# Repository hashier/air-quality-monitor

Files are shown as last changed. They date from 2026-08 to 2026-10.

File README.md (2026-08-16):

# air-quality-monitor

DIY air quality monitor on an ESP32-C6, running ESPHome and reporting to Home Assistant.

## Hardware

- **ESP32-C6** dev board (`esp32-c6-devkitc-1`)
- **Sensirion SCD40**: CO2, temperature, humidity (I2C `0x62`)
- **Sensirion SPS30**: particulate matter PM1.0 / 2.5 / 4.0 / 10.0 (I2C `0x69`, 5V)
- **SSD1306** 128x64 OLED (I2C `0x3C`)
- **WS2812** RGB LED (GPIO8)

All three sensors share one I2C bus at 100 kHz (the SPS30 datasheet ceiling).

## Repo layout

- `esphome/`: firmware (ESPHome config + secrets template)
- `kicad/`: custom PCB (planned)
- `case/`: 3D-printed enclosure (planned)

## Firmware

```fish
cd esphome
cp secrets.yaml.example secrets.yaml   # then fill in real values
esphome run air-quality-monitor.yaml
```

`secrets.yaml` holds WiFi / API / OTA credentials and is gitignored. Never commit it.

## Notes

- **SCD40 auto-recovery:** the sensor can get knocked out of periodic measurement (a flaky power connection resets it). A YAML watchdog detects CO2 going stale and re-inits it over raw I2C (stop, then start). Two Home Assistant diagnostics track this: `CO2 Stall Count` and `CO2 Currently Stalled`.
- **Temperature offset** (`6.5C`) is a provisional self-heating correction for the breadboard build. Re-tune in the final enclosure by comparing side by side against a reference.
- **Warm-up filters** drop the SCD40 startup transient (temperature/humidity 5 min, CO2 30 s).

## Status

Work in progress: currently on a breadboard. Custom PCB and enclosure are next.

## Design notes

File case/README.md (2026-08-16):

# case

3D-printed enclosure for the air quality monitor. Planned.

Design points: passive vents by the SCD40 for ambient diffusion (no direct
draft), a ducted intake and a separate exhaust for the SPS30 fan (kept away
from the SCD40), and the OLED plus RGB LED on the front face.

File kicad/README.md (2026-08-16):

# kicad

Custom PCB design (KiCad) for the air quality monitor. Planned.

Target layout: thermal zoning so the SCD40 sits away from the ESP32 and
regulator heat and the SPS30 exhaust, on a slot-isolated peninsula, with the
SPS30 airflow ducted to separate case vents. See the project notes for details.

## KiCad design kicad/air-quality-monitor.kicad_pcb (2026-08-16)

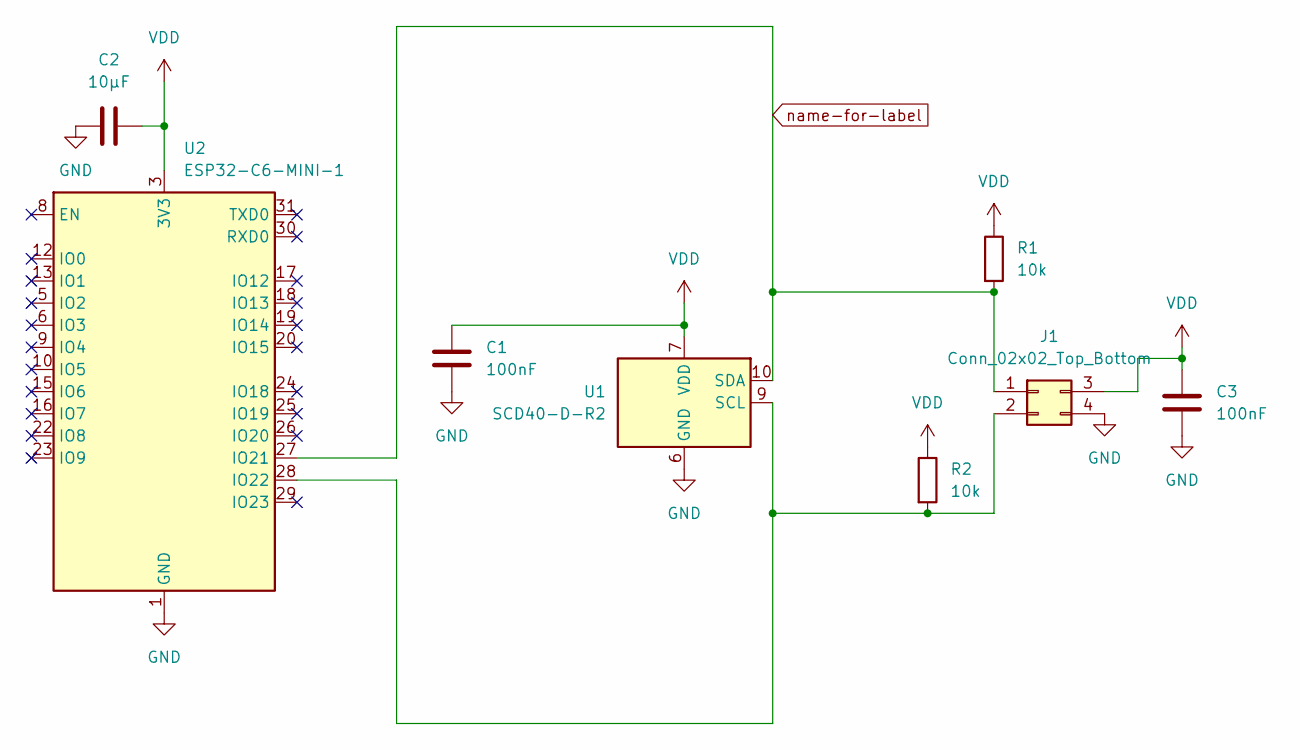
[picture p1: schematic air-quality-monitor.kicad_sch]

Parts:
C1, C3: 100nF; C_0603_1608Metric_Pad1.08x0.95mm_HandSolder
C2: 10µF; C_0603_1608Metric_Pad1.08x0.95mm_HandSolder
J1: Conn_02x02_Top_Bottom; PinHeader_2x02_P2.54mm_Vertical
R1, R2: 10k; R_0603_1608Metric_Pad0.98x0.95mm_HandSolder
U1: SCD40-D-R2; Sensirion_SCD4x-1EP_10.1x10.1mm_P1.25mm_EP4.8x4.8mm
U2: ESP32-C6-MINI-1

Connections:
GND: C1.2, C2.2, C3.2, J1.4, U1.6 (GND), U1.20 (GND), U1.21 (GND), U2.1 (GND), U2.2 (GND), U2.11 (GND), U2.14 (GND), U2.36 (GND), U2.37 (GND), U2.38 (GND), U2.39 (GND), U2.40 (GND), U2.41 (GND), U2.42 (GND), U2.43 (GND), U2.44 (GND), U2.45 (GND), U2.46 (GND), U2.47 (GND), U2.48 (GND), U2.49 (GND), U2.50 (GND), U2.51 (GND), U2.52 (GND), U2.53 (GND)
unnamed: J1.2, R2.2, U1.9 (SCL), U2.28 (IO22)
VDD: C1.1, C2.1, C3.1, J1.3, R1.1, R2.1, U1.7 (VDD), U1.19 (VDD), U2.3 (3V3)
name-for-label: J1.1, R1.2, U1.10 (SDA), U2.27 (IO21)

Board: 2 copper layers, 8 parts (0 on the bottom side), 4 nets, no tracks yet.

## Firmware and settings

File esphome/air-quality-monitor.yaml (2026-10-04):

esphome:
  name: air-quality-monitor
  friendly_name: Air Quality Monitor

esp32:
  # board: esp32-c6-devkitc-1
  # Superseded by variant:. On esp-idf, board: is only the informational
  # ESPHOME_BOARD string and has no effect on the build; variant: selects
  # the actual target.
  variant: esp32c6
  framework:
    type: esp-idf

logger:

api:
  encryption:
    key: !secret aqm_api_key

ota:
  - platform: esphome
    password: !secret aqm_ota_password

wifi:
  # Tried in order, falls back to the next on connection failure
  networks:
    - ssid: !secret wifi_ssid
      password: !secret wifi_password
    - ssid: !secret wifi_hackeriet_ssid
      password: !secret wifi_hackeriet_password

  # Enable fallback hotspot (captive portal) in case wifi connection fails
  ap:
    ssid: "ESPHome"
    password: !secret ap_password

captive_portal:

web_server:
    port: 80

# --- SCD40 stall monitoring + auto-recovery ---
# Watches whether CO2 keeps updating; if it goes stale (sensor knocked out of
# periodic measurement), counts it and re-inits the sensor via raw I2C (stop -> start).
# Fully in YAML now — stock scd4x component, no fork.
globals:
  - id: co2_last_update
    type: uint32_t
    restore_value: no
    initial_value: '0'
  - id: co2_stall_count
    type: int
    restore_value: no
    initial_value: '0'
  - id: co2_in_stall
    type: bool
    restore_value: no
    initial_value: 'false'
  - id: co2_last_recovery
    type: uint32_t
    restore_value: no
    initial_value: '0'

interval:
  - interval: 5s
    then:
      # Detect a stall: CO2 hasn't updated within 2.5x its poll interval (threshold
      # read at runtime so it tracks update_interval with no manual coupling).
      # co2_last_update starts at 0, so until the first reading "elapsed" is the
      # time since boot: a sensor that never delivers at all is caught as well.
      - lambda: |-
          uint32_t elapsed = millis() - id(co2_last_update);
          uint32_t threshold = id(scd40_sensor).get_update_interval() * 5 / 2;
          if (elapsed > threshold && !id(co2_in_stall)) {
            id(co2_in_stall) = true;
            id(co2_stall_count) += 1;
            ESP_LOGW("stall_watch", "CO2 stall #%d (no update for %us)", id(co2_stall_count), (unsigned) (elapsed / 1000));
          }
      # Recover: while stalled, re-init the SCD40 via raw I2C (stop -> 500ms -> start),
      # rate-limited to once per 30s. A successful re-init resumes readings, which
      # clears co2_in_stall via the CO2 on_raw_value.
      - if:
          condition:
            lambda: 'return id(co2_in_stall) && (millis() - id(co2_last_recovery) > 30000);'
          then:
            - lambda: |-
                const uint8_t stop_cmd[2] = {0x3F, 0x86};  // SCD4x stop_periodic_measurement
                id(bus_a).write(0x62, stop_cmd, 2);
                id(co2_last_recovery) = millis();
                ESP_LOGW("stall_watch", "recovery: stop -> start periodic measurement");
            - delay: 500ms
            - lambda: |-
                const uint8_t start_cmd[2] = {0x21, 0xB1};  // SCD4x start_periodic_measurement
                id(bus_a).write(0x62, start_cmd, 2);


# I2C bus - all three devices share this.
# 100kHz is the ceiling: the SPS30 datasheet caps there, so no 400kHz.
i2c:
  id: bus_a
  sda: GPIO21
  scl: GPIO22
  frequency: 100kHz
  scan: true
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

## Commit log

2026-08-16 Initial: air quality monitor with SCD40 C++ fork recovery
    Baseline of the ESP32-C6 air quality monitor (SCD40 CO2, SPS30 PM,
    SSD1306 OLED, RGB LED). SCD40 stall recovery is handled by a local
    patched copy of the scd4x component via external_components: on repeated
    'data not ready' it re-inits the sensor with stop then start.
    Reconstructed from the working config. No version control existed during
    the initial iteration, so this captures the fork-based approach that was
    running on the device rather than a byte-exact snapshot.
    Claude-Session: https://claude.ai/code/session_01N4zAdAqhL2GzWxZfeZSxkv
    [air-quality-monitor.yaml]
2026-08-16 Replace SCD40 C++ fork with YAML raw-I2C recovery
    Drop the forked scd4x component (external_components + components/scd4x)
    in favour of doing the stop/start re-init from a YAML lambda via the i2c
    bus (id: bus_a). Same recovery behaviour on the stock component, so
    nothing needs re-patching across ESPHome updates.
    Also folded in during this session: 6.5C temperature offset for
    self-heating, warm-up filters (temp/humidity 5 min, CO2 30 s), stall
    count + currently-stalled diagnostics, and entity_category grouping.
    Why: the fork was only a thin wrapper adding recovery. Raw i2c writes
    from a lambda achieve the same with far less maintenance surface.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
    [air-quality-monitor.yaml]
2026-08-16 Add README and reserve kicad/ and case/ folders
    Document the project (hardware, layout, build, SCD40 recovery notes) and
    reserve kicad/ (PCB) and case/ (enclosure) for the hardware work to come,
    so this stays a single per-device project repo.
    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
2026-08-16 Track ESPHome's auto-generated esphome/.gitignore
    ESPHome rewrites this file on every config run, so leaving it untracked
    means it shows up as untracked noise in git status forever. The rules
    themselves are already covered by the root .gitignore; this is about
    keeping the working tree clean, not about the ignore coverage.
2026-08-16 Import KiCad project from ~/Documents, unmodified
    Brings the schematic and board under version control so the hardware
    design has the same history as the firmware. Committed under its original
    "test" name deliberately: this is the known-good restore point to fall
    back to if the rename that follows breaks KiCad's internal references.
    Excludes fp-info-cache (4 MB, regenerated by KiCad on demand), the
    auto-saved *-backups/ zips, and *.kicad_prl, which holds per-user editor
    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
    [test.kicad_pcb, test.kicad_sch]
2026-08-16 Rename KiCad project from "test" to air-quality-monitor
    The placeholder name would otherwise leak into every BOM, netlist, and
    gerber export, and renaming gets more disruptive once fabrication outputs
    reference the old name. Doing it now, while the board is still pre-fab.
    Replacements were targeted at the three reference forms rather than a
    blanket search for "test", since that substring can legitimately appear
    in net and footprint names. Verified by re-parsing both files with
    kicad-cli: the schematic exports a netlist of 8 components across 32
    nets, and the board plots to SVG.
    [air-quality-monitor.kicad_pcb, air-quality-monitor.kicad_sch]
2026-08-20 Select the ESP32 target by variant rather than board
    On the esp-idf toolchain, board: never reaches the build: ESPHome only
    uses it as the informational ESPHOME_BOARD string and derives everything
    that matters from the variant. Naming a specific devkit here implied a
    hardware dependency the firmware does not actually have, which is
    misleading while the PCB design is still deciding between a bare module
    and a devkit.
    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
2026-08-20 Expose the SPS30 particle counts and typical particle size
    The SPS30 reports number concentration and typical particle size on
    every measurement cycle alongside the mass concentrations, so these six
    values were already being read off the sensor and thrown away.
    Mass concentration alone cannot distinguish many small particles from a
    few large ones, which is exactly the distinction that identifies a
    source: cooking and candles push the sub-micron counts hard while barely
    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
2026-08-20 Give the SCD40 stall diagnostics proper HA metadata
    Without a state_class, Home Assistant keeps the stall counter in
    short-term recorder history only and never rolls it into long-term
    statistics. That silently defeats the sensor's whole purpose, since the
    question it answers ("did the hardware fix hold?") is one you can only
    see over days or weeks.
    total_increasing rather than measurement because the counter resets to
    zero both on reboot (restore_value: no) and via the reset button. HA
    reads a drop to zero as the start of a new cycle instead of recording a
    large negative delta, whereas measurement would compute min/mean/max
    over a monotonically climbing number and tell you nothing.
    device_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
    [air-quality-monitor.yaml]
2026-08-20 Make typical particle size readable at indoor concentrations
    The sps30 component defaults pm_size to accuracy_decimals: 0, which rounds
    the entire plausible indoor range (roughly 0.3 to 1.4 um) to a single "1".
    The reading looked stuck across hours of logs when it was in fact varying;
    at two decimals the same sensor reports 0.54 um.
    Display only. api_connection.cpp sends the raw float as the state and
    accuracy_decimals separately as entity info, so recorded data is unchanged
    either way. The field is transmitted regardless of this setting, so the
    real choice is which hint to send, not whether to send one.
    [air-quality-monitor.yaml]
2026-08-28 Add ENS160+AHT21 gas/temp/humidity sensors
    Module was initially assumed to be an SGP41 but an I2C scan (0x52 + 0x38)
    identified it as ENS160+AHT21 instead. Compensation uses the AHT21 rather
    than the SCD40 since it's co-located with the ENS160 on the same board.
2026-10-04 Publish 30s averages instead of every 10s reading
    Home Assistant stored a row for each 10s reading, which filled the
    recorder database three times faster than the graphs need and left
    sensor noise in the history. The sensors still sample every 10s, so the
    average smooths noise at no loss of coverage. CO2 gets a small median
    first so a single spike cannot skew the average.
    Two things had to follow from that:
    The CO2 stall watch now stamps on_raw_value. Filtered values arrive
    every 30s, longer than the stall threshold, so watching them would
    report a permanent stall. The watch also no longer skips while no
    reading has arrived, so a sensor that never delivers after boot is
    caught too.
    The di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
    [air-quality-monitor.yaml]
2026-10-28 List a separate SCD40 regulator as something to test
    The SCD40 stalls about once every 50 seconds, and Sensirion recommends
    its own low-noise LDO with at most 30 mV ripple, while today it shares
    the ESP32 board's regulator with the WiFi bursts. Kept under "To test"
    so it only moves into the PCB notes once a breadboard build shows a
    clear drop in the stall count.
2026-10-28 Draft the v1 PCB design and the breadboard tests it depends on
    Collects the decisions from planning a reusable PCB for the living room,
    bedroom and portable builds, so the schematic can be drawn from one place.
    Marked untested: the separate SCD40 regulator and the shared I2C bus still
    have to prove themselves on the breadboard, and the design changes if they
    don't.
2026-10-28 Save the project file in KiCad 10's format
    KiCad 10 rewrote it on close with its new default settings. Committed on its
    own so the schematic commit only holds design changes.
2026-10-28 Draw the v1 schematic from the draft design
    Replaces the placeholder (bare SCD40 chip, ESP32-C6-MINI-1, which can't be
    hand-soldered) with the parts decided in kicad/README.md. KiCad has no
    DevKitC-1 part, so the project library carries its symbol and footprint,
    taken from Espressif's pin list and dimension drawing v1.2. ERC is clean.
2026-10-28 Ignore KiCad's Local History folder
    KiCad 9+ keeps autosave snapshots in kicad/.history/, a git repo of its own.
    The KiCad manual suggests excluding it from version control, and it only
    duplicates what the real commits hold.
2026-10-29 Save the schematic in KiCad 10's format
    Re-saved in the GUI so the first real edit gets a diff of its own
    instead of mixed in with KiCad rewriting every line. Saving also fills
    the project file's sheet uuid, name and revision from the schematic.
2026-10-29 Bridge both 3.3V jumpers to their LDO from the factory
    With open jumpers the 3.3V rails were dead until a blob was soldered.
    Now the board works as delivered, and switching a rail to the dev
    board's 3V3 means cutting the trace and adding a blob.
2026-10-29 Use a jumper cap across D1 so the dev board gets the full 5V
    Behind the Schottky the dev board's 5V pin sees about 4.6V, less than
    the 4.9V that already sent an ESP32-S3 board with the same AMS1117
    into a brownout loop. A cap fails safe: a loose one only puts the
    diode back in the path. It comes off only when both USB cables are in.
2026-10-29 Leave room for bulk capacitors on the dev board's 3V3
    The same S3 board that browned out at 5.0V booted once 100+470µF sat
    on its 3V3 pin. Two optional footprints there keep that fix one
    solder job away, without fitting it on boards that don't need it.
2026-10-29 Give the bulk capacitors the values that fixed the S3 board
    "100-470uF" read as a range for both, while the fix on the S3 board
    was one of each, 100uF plus 470uF.
2026-10-29 Let KiCad place the part labels
    The generator put references and values on top of each other (U1 over
    its value, the R and JP texts). KiCad's Autoplace Fields on the whole
    sheet fixes most of them; saving also added KiCad's simulator defaults
    to the project file.
2026-10-29 Reconnect the dev board's 3V3 pin
    The previous commit carried U3 pin 1's wire stub moved off to the top
    of the sheet, so pin 1 was connected to nothing and DEV_3V3 dangled.
    ERC flagged it; the wire is back where it was in ef42f9d.
2026-10-29 Space out the dev board jumpers and bulk capacitors
    After Autoplace Fields each jumper's reference sat on the pads of the
    one above, and the C6/C7 note touched their labels. 10.16 mm between
    the jumpers leaves room for both texts above each.
2026-10-30 Move J3's GND symbol clear of the 3V3_AUX label
    The arrow sat on top of the label below it, which made the pin's net hard to read.
2026-10-30 Show C2 and C4 at the VIN pins they belong to
    Each input cap has to sit next to its own regulator's VIN pin on the board. Wiring them there on the sheet carries that over to layout, and drops the +5V symbols that became redundant.
2026-10-30 Rename the dev board header nets to DEVPIN_*
    DEV_3V3 and 3V3_DEV were one character shuffle apart but sit on opposite sides of JP4, which makes the two easy to mix up.
2026-10-30 Show the power direction in the dev board net names
    3V3_DEV comes out of the dev board and 5V_DEV goes into it, but the two names looked the same.
2026-10-30 Say why the extra I2C pull-ups stay unfitted
    The note only said the bus test decides, which hid that the SCD40 breakout already pulls the bus up. Moved up as well, because its second line ran into the 3V3_AUX labels.
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2026-11-10 Use the USB-C breakout board as J1
    The breakout picked on 2026-10-30 replaces the GCT surface-mount socket.
    It goes in through an ordinary 2.54 mm header and carries its own 5.1k
    on CC1/CC2, so R1 and R2 go as well. J7 was only there to compare the
    two. Pin order comes from the listing until the board arrives.
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2026-11-10 Make C2 to C5 through-hole
    The hackerspace has through-hole capacitors, but their lead spacing
    isn't measured yet. The 4-hole footprint takes leads 2.5 mm or 5 mm
    apart, so the board doesn't wait on that.
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
